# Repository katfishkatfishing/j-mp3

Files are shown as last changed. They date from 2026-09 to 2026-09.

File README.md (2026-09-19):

# J-mp3

<h2>Portable Music Player</h2>

<p align="center">
  <a href="https://github.com/user-attachments/assets/98f374b8-415b-4eb8-9580-ea03950c9d8b">
    J-mp3 Portable Music Player
  </a>
</p>
      <p>Making my own portable music player!</p>
      <p>I recently got interested in making my own electronics, and one day, I saw the Teenage Engineering TP7 field recorder. I loved the design it had, and wanted one. But I checked the price and it was wayy too expensive, so I decided to make my own, just only with the audio playing part and without the cool fancy stuff. I'm very new to this, so I couldn't replicate it very well, pls don't be too harsh on my work lol, but please feel free to give me any advice.</p>
      <p>A portable music player inspired by classic iPods, and trying to match the design style of Teenage Engineering, playing audio directly from an inserted microSD card with support for both high-fidelity analog 3.5mm output and Bluetooth audio streaming.</p>
      <p> ⚡Powered by the <strong>ESP32-S31</strong> and PCM5102A Audio DAC</p>
      <p>More projects and revisions coming soon🙏!</p>
      <p>Note: I know the rotary encoder knob is off and too long, but I temporarily have no solutions for that. 💔</p>

## Capabilities
### Microcontroller & Audio
- **ESP32-S31** (ESP32-S31 embedded, RISC-V 32-bit dual-coremicroprocessor, up to 320 MHz, 2.4 GHz Wi-Fi & Bluetooth 5.4 (LE))
- **PCM5102A** Audio Stereo DAC (32-bit, 384kHz high-resolution audio)
- **TDA1308** Class-AB stereo headphone driver amplifier
- **PJ-320B** 3.5mm headphone jack with analog output & Bluetooth audio support

### Display, Controls & Storage
- **1.73" AMOLED Display** (466×466 resolution via high-speed QSPI)
- **EC11E Rotary Encoder** with integrated push button for scroll navigation
- **MicroSD Card Socket** (Hirose DM3AT push-push) for onboard music storage

### Power & Battery Management
- **TP4056** Li-Ion battery charging IC with thermistor temperature sensing
- **DW01A + FS8205A** integrated battery protection (overcharge, overdischarge, overcurrent)
- **TPS2121** Power Multiplexer / Ideal Diode Controller (seamless automatic switching between USB-C and battery)
- **TPS61023** Synchronous boost converter & low-noise **RT9080-33** LDO regulators
- Supports 3.7V LiPo battery (705050 3000mAh)
- USB Type-C receptacle for charging and power input

## J-mp3 PCB
### Schematic
J-mp3 Schematic 1

J-mp3 Schematic 2

J-mp3 Schematic 3

J-mp3 Schematic 4

## BOM

| Item | Parts | Qty. | Price per lot (USD) | Source |
| :--- | :--- | :--- | :--- | :--- |
| Audio jack female | PJ-320B | 1 | 3.27 | https://www.aliexpress.com/item/1005010463642476.html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 |
| Dual N-channel MOSFET | FS8205A | 1 | 1.59 | https://www.aliexpress.com/item/1005006375737459.html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 |
| Ideal Diode Controller | TPS2121RUXR | 1 | 2.09 | https://www.aliexpress.com/item/1005010183114644.html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 |
| ESP32 MCU unit | ESP32-S31-WROOM-3 | 1 | 5.00 | https://www.aliexpress.com/item/1005012434557649.html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 |
| Boost Voltage Converter | TPS61023DRLR | 1 | 0.18 | https://www.aliexpress.com/item/1005008589999406.html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 |
| Ceramic capacitor SMD | 1uF 0402 | 8 | 2.04 | https://www.aliexpress.com/item/1005012364450156.html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 |
| P-Channel MOSFET | AO3401A | 1 | 1.99 | https://www.aliexpress.com/item/1005008388291353.html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 |
| Diode | 1N4148 | 2 | 1.97 | https://www.aliexpress.com/item/1005007160563285.html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 |
| Audio Stereo DAC | PCM5102A | 1 | 4.46 | https://www.aliexpress.com/item/1005006267865363.html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 |
| Headphone Driver Amplifier | TDA1308 | 1 | 2.08 | https://www.aliexpress.com/item/33051574290.html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 |
| Bipolar transistor symbol | NPN SOT-23 | 1 | 5.12 | https://www.aliexpress.com/item/1005012628572946.html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 |
| Generic connector, 02x12 | Conn_02x12_Counter_Clockwise | 1 | 1.50 | https://www.aliexpress.com/item/1005007611939409.html |
| Generic connector, 01x04 | Conn_01x04_Pin | 1 | 1.17 | https://www.aliexpress.com/item/1005012793102722.html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 |
| Inductor SMD | 2.2uH 0603 | 1 | 2.14 | https://www.aliexpress.com/item/1005004840798951.html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 |
| Linear Voltage Regulator | RT9080-33GJ5 | 2 | 1.53 | https://www.aliexpress.com/item/1005004159688937.html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 |
| Micro SD Card Socket | Hirose DM3AT-SF-PEJM5 | 1 | 1.20 | https://www.aliexpress.com/item/1005008529231123.html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 |
| Battery protection | DW01A | 1 | 2.54 | https://www.aliexpress.com/item/1005008626342372.html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 |
| Capacitor Tantalum SMD | 100uF 3528-12 (Metric) | 1 | 4.05 | https://my.mouser.com/en/ProductDetail/Vishay-Sprague/293D107X9004B2TE3?qs=N31o%252Bt096guiYtrI%2FhDC5g%3D%3D |
| Capacitor Tantalum SMD | 10uF 0603 | 4 | 9.68 | https://www.aliexpress.com/item/1005003344584575.html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 |
| Push button switch | SW-SMD_TC-1101V-C-B-W | 1 | 0.40 | https://item.szlcsc.com/300030.html |
| Push button switch SMD | SW_SPST_B3U-1000P | 2 | 1.46 | https://www.aliexpress.com/item/1005009548875400.html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 |
| Ceramic resistor SMD | 10k 0805 | 13 | 1.99 | https://www.aliexpress.com/item/1005007183002569.html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 |
| Ceramic resistor SMD | 2k 0603 | 1 | 1.80 | https://www.aliexpress.com/item/1005003529112557.html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 |
| Ceramic resistor SMD | 82k 0805 | 1 | 2.03 | https://www.aliexpress.com/item/1005007183002569.html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 |
| Ceramic resistor SMD | 100 0402 | 1 | 1.38 | https://www.aliexpress.com/item/1005003721873929.html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 |
| Ceramic resistor SMD | 3.9k 0402 | 4 | 1.38 | https://www.aliexpress.com/item/1005003721873929.html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 |
| Ceramic resistor SMD | 1m 0603 | 1 | 1.48 | https://www.aliexpress.com/item/1005010109041806.html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 |
| Ceramic resistor SMD | 5k1 0603 | 2 | 1.75 | https://www.aliexpress.com/item/1005003529112557.html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 |
| Ceramic resistor SMD | 1k 0402 | 1 | 1.38 | https://www.aliexpress.com/item/1005003721873929.html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 |
| Ceramic resistor SMD | 100k 0805 | 6 | 2.00 | https://www.aliexpress.com/item/1005007183002569.html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 |
| Ceramic resistor SMD | 4.7k 0805 | 1 | 2.00 | https://www.aliexpress.com/item/1005007183002569.html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 |
| Ceramic resistor SMD | 470 0603 | 2 | 1.80 | https://www.aliexpress.com/item/1005003529112557.html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 |
| Ceramic resistor SMD | 43k 0805 | 1 | 2.03 | https://www.aliexpress.com/item/1005007183002569.html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 |
| Ceramic resistor SMD | 732k 0603 | 1 | 2.10 | https://www.aliexpress.com/item/1005005459557840.html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 |
| Rotary encoder with switch | EC11E | 1 | 2.94 | https://www.aliexpress.com/item/32976046900.html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 |
| Single-cell battery | 755060 LiPo 3000mAh | 1 | 8.90 | https://www.aliexpress.com/item/1005006259194674.html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 |
| Li-lon Battery Charger | TP4056 | 1 | 0.52 | https://www.aliexpress.com/item/1005005487915175.html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 |
| Thermistor | 10k 0402 | 1 | 2.81 | https://www.aliexpress.com/item/1005010466857933.html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 |
| Ceramic capacitor SMD | 100nF 0603 | 4 | 2.01 | https://www.aliexpress.com/item/1005007660078779.html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 |
| Ceramic capacitor SMD | 10uF 0805 | 5 | 2.64 | https://www.aliexpress.com/item/1005012364450156.html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 |
| Ceramic capacitor SMD | 1uF 0805 | 3 | 2.35 | https://www.aliexpress.com/item/1005012364450156.html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 |
| Ceramic capacitor SMD | 10nF 0603 | 1 | 2.00 | https://www.aliexpress.com/item/1005007660078779.html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 |
| Ceramic capacitor SMD | 22uF 0805 | 3 | 3.55 | https://www.aliexpress.com/item/1005012364450156.html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 |
| Ceramic capacitor SMD | 0.1uF 0805 | 2 | 1.43 | https://www.aliexpress.com/item/1005006142309480.html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 |
| Ceramic capacitor SMD | 100uF 0805 | 2 | 13.72 | https://www.aliexpress.com/item/1005005590636993.html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 |
| Ceramic capacitor SMD | 0.1uF 0201 | 4 | 0.95 | https://www.aliexpress.com/item/1005008499718166.html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 |
| Ceramic capacitor SMD | 2.2uF 0603 | 2 | 2.03 | https://www.aliexpress.com/item/1005007660078779.html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 |
| Ceramic capacitor SMD | 1nF 0603 | 1 | 1.98 | https://www.aliexpress.com/item/1005007660078779.html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 |
| Ceramic capacitor SMD | 2.2nF 0805 | 2 | 3.04 | https://www.aliexpress.com/item/33039604868.html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 |
| Ceramic capacitor SMD | 100pF 0603 | 1 | 2.03 | https://www.aliexpress.com/item/1005007660078779.html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 |
| USBType-C Receptacle | USB4125-GF-A | 1 | 0.60 | https://www.digikey.my/en/products/detail/gct/USB4125-GF-A/13547388 |
| AMOLED Display | 1.73 inch 466x466 QSPI | 1 | 7.47 | https://item.taobao.com/item.htm?id=952177467095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 |
| Total+Shipping+Tax | - | - | 139.55± | - |

### Footprint
<table>
  <tr>
    <td>
      J-mp3 Footprint Front
    </td>
    <td>
      J-mp3 Footprint Back
    </td>
  </tr>
  <tr>
    <td>
      J-mp3 Inner Layer 1
    </td>
    <td>
      J-mp3 Inner Layer 2
    </td>
  </tr>
</table>

### 3D View
<table>
  <tr>
    <td>
      J-mp3 PCB Top
    </td>
    <td>
      J-mp3 PCB Bottom
    </td>
  </tr>
  <tr>
    <td>
      J-mp3 Enclosure Top
    </td>
    <td>
      J-mp3 Enclosure Bottom
    </td>
  </tr>
  <tr>
    <td>
      J-mp3 Enclosure Side 1
    </td>
    <td>
      J-mp3 Enclosure Side 2
    </td>
  </tr>
</table>

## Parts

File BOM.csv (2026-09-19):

Description | Value | Qty | Price per lot(USD) | Source
Audio jack female | PJ-320B | 1 | 3.27 | https://www.aliexpress.com/item/1005010463642476.html
Dual N-channel MOSFET | FS8205A | 1 | 1.59 | https://www.aliexpress.com/item/1005006375737459.html
Ideal Diode Controller | TPS2121RUXR | 1 | 2.09 | https://www.aliexpress.com/item/1005010183114644.html
ESP32 MCU unit | ESP32-S31-WROOM-3 | 1 | 5.00 | https://www.aliexpress.com/item/1005012434557649.html?srcSns=sns_Copy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
Boost Voltage Converter | TPS61023DRLR | 1 | 0.18 | https://www.aliexpress.com/item/1005008589999406.html
Ceramic capacitor SMD | 1uF 0402 | 8 | 2.04 | https://www.aliexpress.com/item/1005012364450156.html
P-Channel MOSFET | AO3401A | 1 | 1.99 | https://www.aliexpress.com/item/1005008388291353.html
Diode | 1N4148 | 2 | 1.97 | https://www.aliexpress.com/item/1005007160563285.html
Audio Stereo DAC | PCM5102A | 1 | 4.46 | https://www.aliexpress.com/item/1005006267865363.html?scm_id=1007.40050.354490.0&scm-url=1007.40050.354490.0
Headphone Driver Amplifier | TDA1308 | 1 | 2.08 | https://www.aliexpress.com/item/33051574290.html
Bipolar transistor symbol | NPN SOT-23 | 1 | 5.12 | https://www.aliexpress.com/item/1005012628572946.html
Generic connector, 02x12 | Conn_02x12_Counter_Clockwise | 1 | 1.50 | https://www.aliexpress.com/item/1005007611939409.html
Generic connector, 01x04 | Conn_01x04_Pin | 1 | 1.17 | https://www.aliexpress.com/item/1005012793102722.html
Inductor SMD | 2.2uH 0603 | 1 | 2.14 | https://www.aliexpress.com/item/1005004840798951.html
Linear Voltage Regulator | RT9080-33GJ5 | 2 | 1.53 | https://www.aliexpress.com/item/1005004159688937.html
Micro SD Card Socket | Hirose DM3AT-SF-PEJM5 | 1 | 1.20 | https://www.aliexpress.com/item/1005008529231123.html
Battery protection | DW01A | 1 | 2.54 | https://www.aliexpress.com/item/1005008626342372.html
Capacitor Tantalum SMD | 100uF 3528-12 (Metric) | 1 | 4.05 | https://my.mouser.com/en/ProductDetail/Vishay-Sprague/293D107X9004B2TE3?qs=N31o%252Bt096guiYtrI%2FhDC5g%3D%3D
Capacitor Tantalum SMD | 10uF 0603 | 4 | 9.68 | https://www.aliexpress.com/item/1005003344584575.html
Push button switch | SW-SMD_TC-1101V-C-B-W | 1 | 0.40 | https://item.szlcsc.com/300030.html
Push button switch SMD | SW_SPST_B3U-1000P | 2 | 1.46 | https://www.aliexpress.com/item/1005009548875400.html
Ceramic resistor SMD | 10k 0805 | 13 | 1.99 | https://www.aliexpress.com/item/1005007183002569.html
Ceramic resistor SMD | 2k 0603 | 1 | 1.80 | https://www.aliexpress.com/item/1005003529112557.html
Ceramic resistor SMD | 82k 0805 | 1 | 2.03 | https://www.aliexpress.com/item/1005007183002569.html
Ceramic resistor SMD | 100 0402 | 1 | 1.38 | https://www.aliexpress.com/item/1005003721873929.html
Ceramic resistor SMD | 3.9k 0402 | 4 | 1.38 | https://www.aliexpress.com/item/1005003721873929.html
Ceramic resistor SMD | 1m 0603 | 1 | 1.48 | https://www.aliexpress.com/item/1005010109041806.html
Ceramic resistor SMD | 5k1 0603 | 2 | 1.75 | https://www.aliexpress.com/item/1005003529112557.html
Ceramic resistor SMD | 1k 0402 | 1 | 1.38 | https://www.aliexpress.com/item/1005003721873929.html
Ceramic resistor SMD | 100k 0805 | 6 | 2.00 | https://www.aliexpress.com/item/1005007183002569.html
Ceramic resistor SMD | 4.7k 0805 | 1 | 2.00 | https://www.aliexpress.com/item/1005007183002569.html
Ceramic resistor SMD | 470 0603 | 2 | 1.80 | https://www.aliexpress.com/item/1005003529112557.html
Ceramic resistor SMD | 43k 0805 | 1 | 2.03 | https://www.aliexpress.com/item/1005007183002569.html
Ceramic resistor SMD | 732k 0603 | 1 | 2.10 | https://www.aliexpress.com/item/1005005459557840.html
Rotary encoder with switch | EC11E | 1 | 2.94 | https://www.aliexpress.com/item/32976046900.html?scm_id=1007.14452.396806.0&scm-url=1007.14452.396806.0
Single-cell battery | 405070 LiPo 3000mAh | 1 | 8.90 | https://www.aliexpress.com/item/1005006259194674.html
Li-lon Battery Charger | TP4056 | 1 | 0.52 | https://www.aliexpress.com/item/1005005487915175.html
Thermistor | 10k 0402 | 1 | 2.81 | https://www.aliexpress.com/item/1005010466857933.html
Ceramic capacitor SMD | 100nF 0603 | 4 | 2.01 | https://www.aliexpress.com/item/1005007660078779.html
Ceramic capacitor SMD | 10uF 0805 | 5 | 2.64 | https://www.aliexpress.com/item/1005012364450156.html
Ceramic capacitor SMD | 1uF 0805 | 3 | 2.35 | https://www.aliexpress.com/item/1005012364450156.html
Ceramic capacitor SMD | 10nF 0603 | 1 | 2.00 | https://www.aliexpress.com/item/1005007660078779.html
Ceramic capacitor SMD | 22uF 0805 | 3 | 3.55 | https://www.aliexpress.com/item/1005012364450156.html
Ceramic capacitor SMD | 0.1uF 0805 | 2 | 1.43 | https://www.aliexpress.com/item/1005006142309480.html
Ceramic capacitor SMD | 100uF 0805 | 2 | 13.72 | https://www.aliexpress.com/item/1005005590636993.html
Ceramic capacitor SMD | 0.1uF 0201 | 4 | 0.95 | https://www.aliexpress.com/item/1005008499718166.html
Ceramic capacitor SMD | 2.2uF 0603 | 2 | 2.03 | https://www.aliexpress.com/item/1005007660078779.html
Ceramic capacitor SMD | 1nF 0603 | 1 | 1.98 | https://www.aliexpress.com/item/1005007660078779.html
Ceramic capacitor SMD | 2.2nF 0805 | 2 | 3.04 | https://www.aliexpress.com/item/33039604868.html
Ceramic capacitor SMD | 100pF 0603 | 1 | 2.03 | https://www.aliexpress.com/item/1005007660078779.html
USBType-C Receptacle | USB4125-GF-A | 1 | 0.60 | https://www.digikey.my/en/products/detail/gct/USB4125-GF-A/13547388
AMOLED Display | 1.73 inch 466x466 QSPI | 1 | 7.47 | https://item.taobao.com/item.htm?id=952177467095&xxc=shop

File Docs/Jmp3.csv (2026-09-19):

Reference | Qty | Value | Footprint | Datasheet
Audio1 | 1 | PJ-320B | easyeda2kicad:AUDIO-SMD_PJ-320B_C2884998 | https://lcsc.com/product-detail/Audio-Connectors_3-5mmCloth-headphone-jack_C18594.html
BT1 | 1 | 755060 LiPo 3000mAh | Connector_JST:JST_EH_S2B-EH_1x02_P2.50mm_Horizontal
C16 | 1 | 10nF | Capacitor_SMD:C_0603_1608Metric_Pad1.08x0.95mm_HandSolder
C22 | 1 | 100uF | Capacitor_Tantalum_SMD:CP_EIA-3528-12_Kemet-T_HandSolder
C37 | 1 | 1nF | Capacitor_SMD:C_0603_1608Metric_Pad1.08x0.95mm_HandSolder
C40 | 1 | 0.1nF | Capacitor_SMD:C_0603_1608Metric_Pad1.08x0.95mm_HandSolder
J2 | 1 | USB_C_Receptacle_PowerOnly_6P | Connector_USB:USB_C_Receptacle_GCT_USB4125-xx-x-0190_6P_TopMnt_Horizontal | https://www.usb.org/sites/default/files/documents/usb_type-c.zip
J4 | 1 | Micro_SD_Card_Det2 | Connector_Card:microSD_HC_Hirose_DM3AT-SF-PEJM5 | https://www.hirose.com/en/product/document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
J5 | 1 | Conn_01x04_Pin | Connector_PinHeader_1.00mm:PinHeader_1x04_P1.00mm_Horizontal
J6 | 1 | Conn_02x12_Counter_Clockwise | OK-23GM024-04:CONN-SMD_OK-23GM024-04
L1 | 1 | 2.2uH | Inductor_SMD:L_0603_1608Metric_Pad1.05x0.95mm_HandSolder
Q1 | 1 | FS8205A | FS8205A:SOP65P640X120-8N
Q2 | 1 | NPN | PCM_JLCPCB:Q_SOT-23 | https://ngspice.sourceforge.io/docs/ngspice-html-manual/manual.xhtml#cha_BJTs
Q3 | 1 | AO3401A | Package_TO_SOT_SMD:SOT-23 | http://www.aosmd.com/pdfs/datasheet/AO3401A.pdf
R6 | 1 | 2k | Resistor_SMD:R_0603_1608Metric_Pad0.98x0.95mm_HandSolder
R7 | 1 | 82k | Resistor_SMD:R_0805_2012Metric_Pad1.20x1.40mm_HandSolder
R8 | 1 | 100 | Resistor_SMD:R_0402_1005Metric_Pad0.72x0.64mm_HandSolder
R11 | 1 | 1m | Resistor_SMD:R_0603_1608Metric_Pad0.98x0.95mm_HandSolder
R15 | 1 | 1k | Resistor_SMD:R_0402_1005Metric_Pad0.72x0.64mm_HandSolder
R21 | 1 | 4.7k | Resistor_SMD:R_0805_2012Metric_Pad1.20x1.40mm_HandSolder
R33 | 1 | 43k | Resistor_SMD:R_0805_2012Metric_Pad1.20x1.40mm_HandSolder
R37 | 1 | 732k | Resistor_SMD:R_0603_1608Metric_Pad0.98x0.95mm_HandSolder
SW1 | 1 | Power Button | sidebutton:SW-SMD_TC-1101V-C-B-W
SW2 | 1 | RotaryEncoder_Switch | Rotary_Encoder:RotaryEncoder_Alps_EC11E-Switch_Vertical_H20mm
TH1 | 1 | 10k | THERM:THERM_NTCG103JF103FT1
U1 | 1 | TP4056 | Package_SO:SOP-8-1EP_4.57x4.57mm_P1.27mm_EP4.57x4.45mm | https://datasheet.lcsc.com/szlcsc/1906261508_Nanjing-Extension-Microelectronics-TP4056-42-ESOP8_C16581.pdf
U2 | 1 | TPS2121RUXR | footprints:RUX0012A | https://www.ti.com/lit/gpn/tps2121
U3 | 1 | DW01A | Package_TO_SOT_SMD:SOT-23-6 | https://hmsemi.com/downfile/DW01A.PDF
U4 | 1 | TDA1308 | TDA1308:SO8
U5 | 1 | PCM5102A | Package_SO:TSSOP-20_4.4x6.5mm_P0.65mm | https://www.ti.com/lit/ds/symlink/pcm5102a.pdf
U6 | 1 | ESP32-S31-WROOM-3_C9900281993 | Library:esp32s31wroom3 | https://www.lcsc.com/datasheet/C9900281993.pdf
U7 | 1 | TPS61023DRLR | TPS61023:DRL0006A | https://www.ti.com/lit/gpn/tps61023
C21,C23 | 2 | 0.1uF | Capacitor_SMD:C_0805_2012Metric_Pad1.18x1.45mm_HandSolder
C25,C26 | 2 | 100uF | Capacitor_SMD:C_0805_2012Metric_Pad1.18x1.45mm_HandSolder
C33,C34 | 2 | 2.2uF | Capacitor_SMD:C_0603_1608Metric_Pad1.08x0.95mm_HandSolder
C38,C39 | 2 | 2.2nF | Capacitor_SMD:C_0805_2012Metric_Pad1.18x1.45mm_HandSolder
D1,D2 | 2 | 1N4148 | Diode_SMD:D_SOD-323 | https://assets.nexperia.com/documents/data-sheet/1N4148_1N4448.pdf
IC1,IC2 | 2 | RT9080-33GJ5 | RT9080-33:SOT94P280X100-5N
R13,R14 | 2 | 5k1 | Resistor_SMD:R_0603_1608Metric_Pad0.98x0.95mm_HandSolder
R23,R24 | 2 | 470 | Resistor_SMD:R_0603_1608Metric_Pad0.98x0.95mm_HandSolder
SW3,SW4 | 2 | SW_Push | Button_Switch_SMD:SW_SPST_B3U-1000P
C14,C20,C41 | 3 | 1uF | Capacitor_SMD:C_0805_2012Metric_Pad1.18x1.45mm_HandSolder
C19,C45,C46 | 3 | 22uF | Capacitor_SMD:C_0805_2012Metric_Pad1.18x1.45mm_HandSolder
C2,C13,C15,C43 | 4 | 100nF | Capacitor_SMD:C_0603_1608Metric_Pad1.08x0.95mm_HandSolder
C27,C29,C31,C36 | 4 | 10uF | Capacitor_SMD:C_0603_1608Metric_Pad1.08x0.95mm_HandSolder
C28,C30,C32,C35 | 4 | 0.1uF | Capacitor_SMD:C_0201_0603Metric_Pad0.64x0.40mm_HandSolder
R9,R10,R19,R20 | 4 | 3.9k | Resistor_SMD:R_0402_1005Metric_Pad0.72x0.64mm_HandSolder
C3,C10,C18,C44,C47 | 5 | 10uF | Capacitor_SMD:C_0805_2012Metric_Pad1.18x1.45mm_HandSolder
R2,R12,R16,R22,R34,R38 | 6 | 100k | Resistor_SMD:R_0805_2012Metric_Pad1.20x1.40mm_HandSolder
C1,C4,C5,C11,C12,C17,C24,C42 | 8 | 1uF | Capacitor_SMD:C_0402_1005Metric_Pad0.74x0.62mm_HandSolder
R1,R17,R18,R25,R26,R27,R28,R29,R30,R31,R32,R35,R36 | 13 | 10k | Resistor_SMD:R_0805_2012Metric_Pad1.20x1.40mm_HandSolder

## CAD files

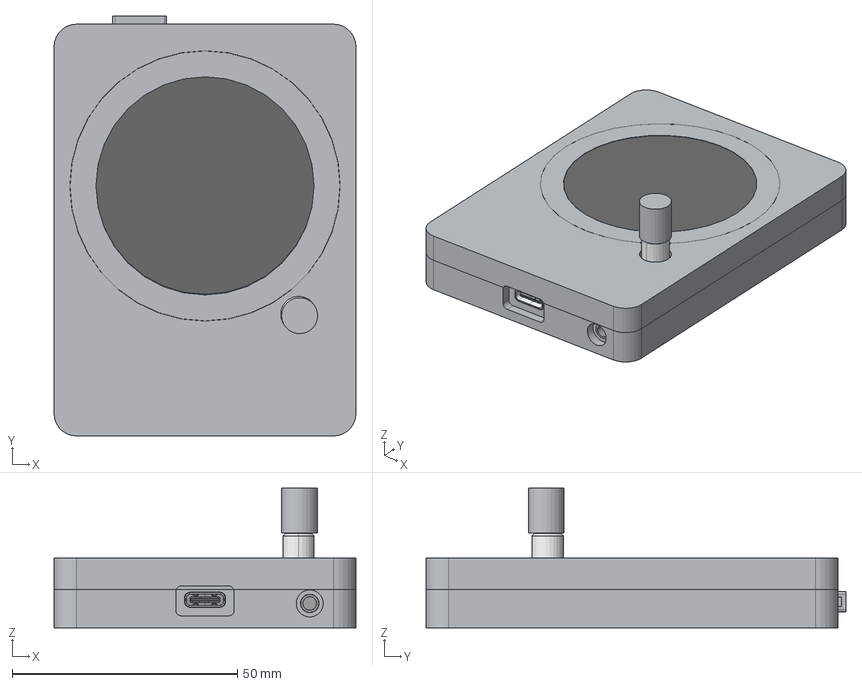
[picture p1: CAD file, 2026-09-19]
3D model/jmp3case.step
67.0 x 93.2 x 31.0 mm
Battery
C_0603_1608Metric
C_0805_2012Metric
C_0603_1608Metric002
C_0201_0603Metric
R_0603_1608Metric
R_0805_2012Metric
C_0201_0603Metric002
C_0603_1608Metric004
R_0805_2012Metric002
R_0603_1608Metric002
R_0603_1608Metric004
C_0402_1005Metric
C_0805_2012Metric002
C_0805_2012Metric004
R_0805_2012Metric004
C_0402_1005Metric002
C_0805_2012Metric006
C_0201_0603Metric004
R_0603_1608Metric006
C_0805_2012Metric008
D_SOD-323
C_0805_2012Metric010
R_0805_2012Metric006
R_0402_1005Metric
C_0805_2012Metric012
R_0805_2012Metric008
R_0402_1005Metric002
C_0805_2012Metric014
R_0805_2012Metric010
R_0402_1005Metric004
C_0805_2012Metric016
R_0805_2012Metric012
R_0805_2012Metric014
胈陆胈陋胈卤谩耞芦胈路EC11E-05SW
SOT_23
C_0805_2012Metric018
PinHeader_1x04_P100mm_Horizontal
SOT-23-6
R_0805_2012Metric016
C_0201_0603Metric006
C_0805_2012Metric020
R_0402_1005Metric006
C_0805_2012Metric022
C_0805_2012Metric024
C_0402_1005Metric004
C_0603_1608Metric006
R_0805_2012Metric018
L_0603_1608Metric
R_0805_2012Metric020
R_0805_2012Metric022
C_0603_1608Metric008
C_0603_1608Metric010
R_0805_2012Metric024
C_0402_1005Metric006
R_0805_2012Metric026
C_0603_1608Metric012
C_0805_2012Metric026
R_0805_2012Metric028
C_0603_1608Metric014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

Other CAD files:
3D model/J-mp3.step

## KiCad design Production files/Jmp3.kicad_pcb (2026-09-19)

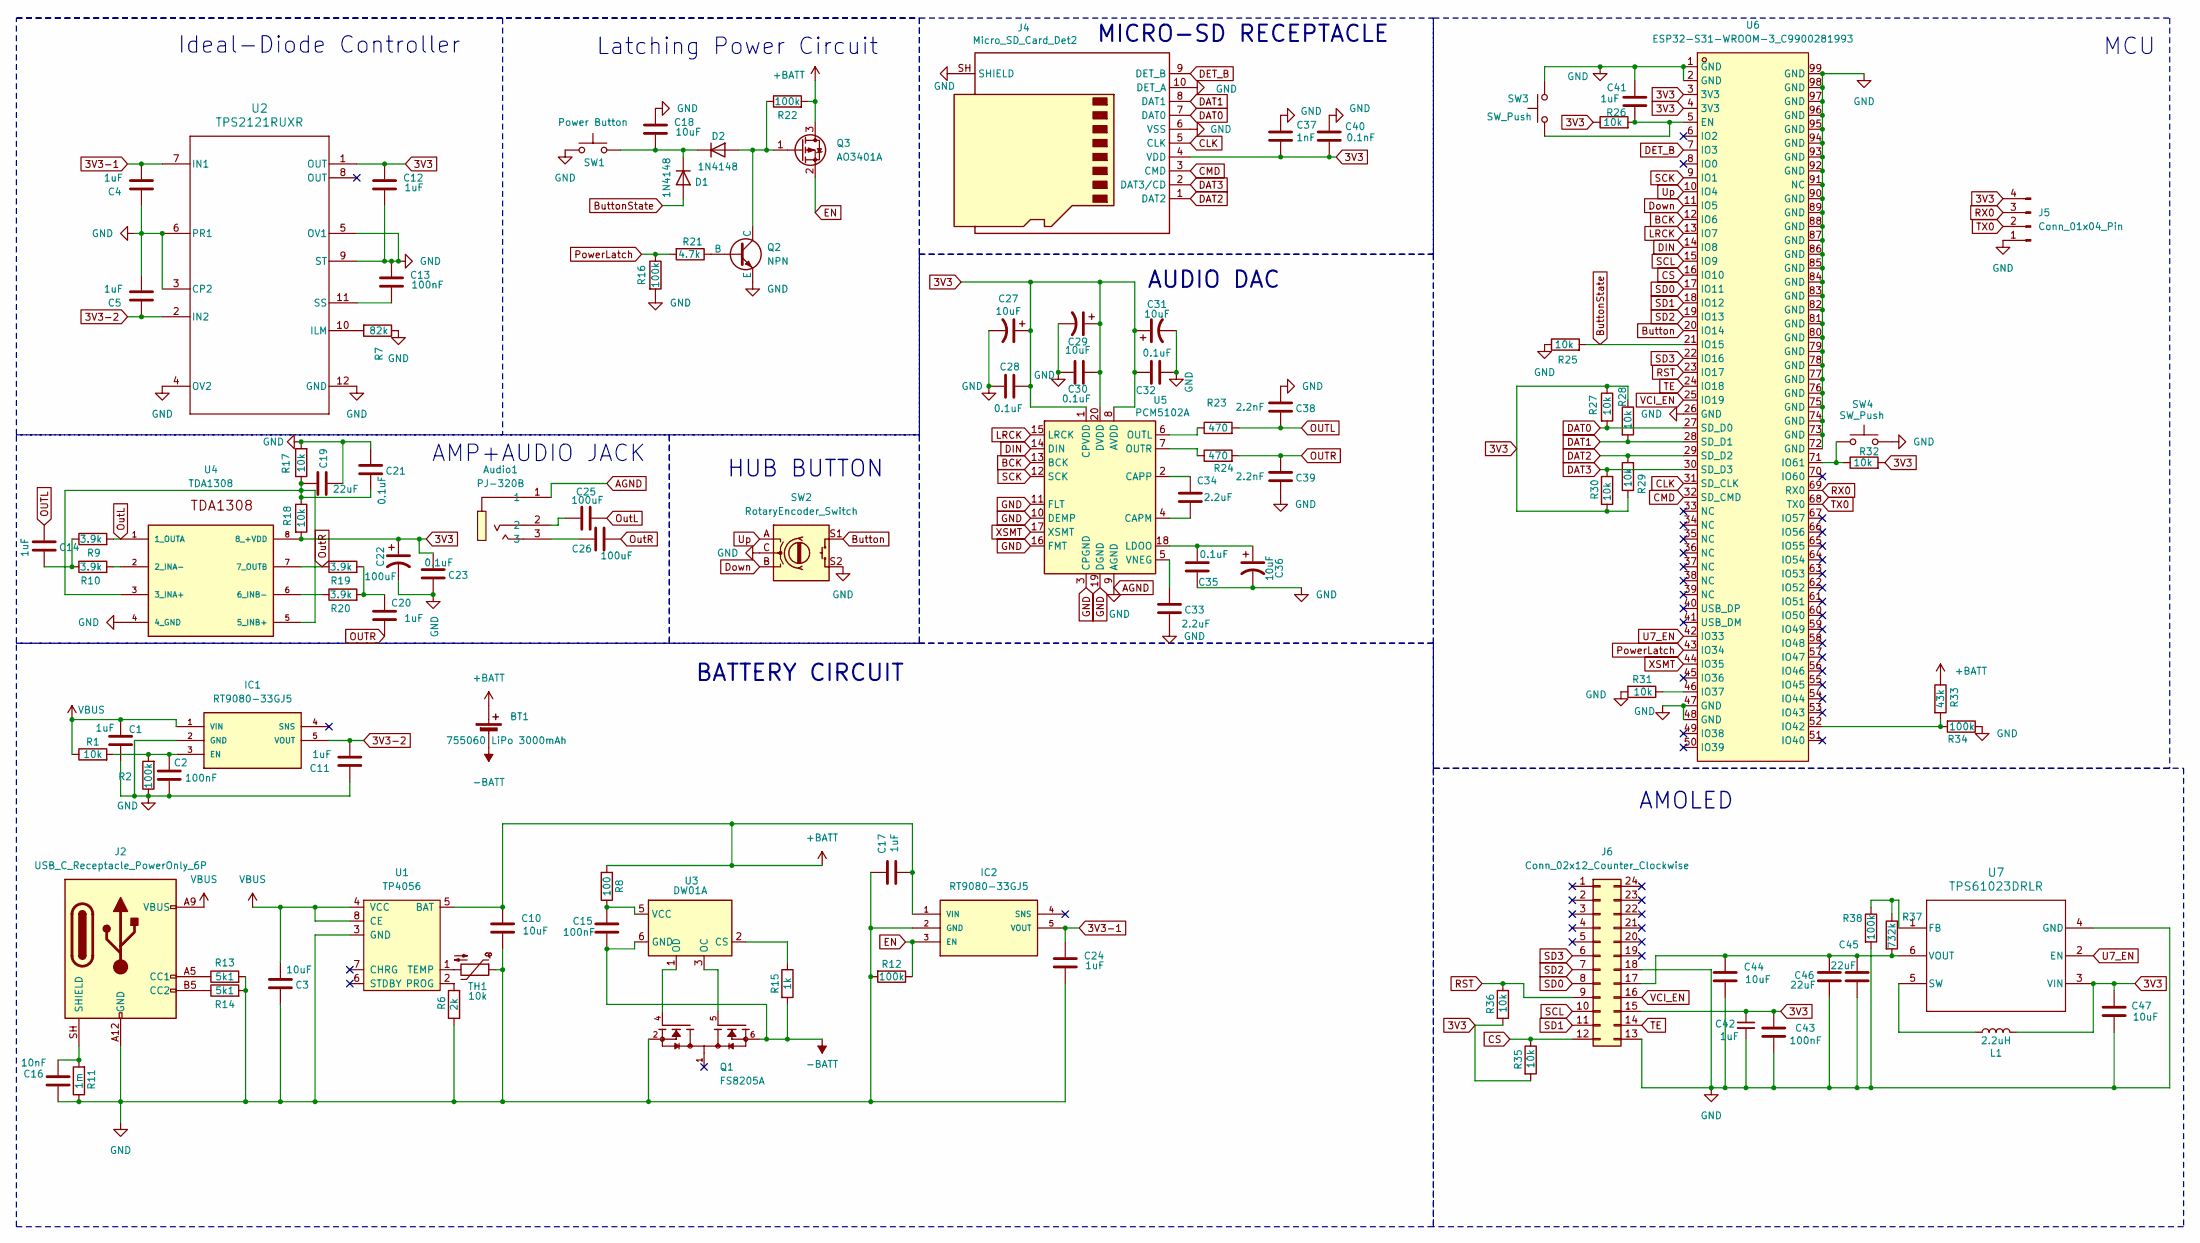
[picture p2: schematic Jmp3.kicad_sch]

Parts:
Audio1: PJ-320B; AUDIO-SMD_PJ-320B_C2884998; MPN PJ-320B贴片; LCSC Part C18594
BT1: 755060 LiPo 3000mAh; JST_EH_S2B-EH_1x02_P2.50mm_Horizontal
C1, C4, C5, C11, C12, C17, C24, C42: 1uF; C_0402_1005Metric_Pad0.74x0.62mm_HandSolder
C2, C13, C15, C43: 100nF; C_0603_1608Metric_Pad1.08x0.95mm_HandSolder
C3, C10, C18, C44, C47: 10uF; C_0805_2012Metric_Pad1.18x1.45mm_HandSolder
C14, C20, C41: 1uF; C_0805_2012Metric_Pad1.18x1.45mm_HandSolder
C16: 10nF; C_0603_1608Metric_Pad1.08x0.95mm_HandSolder
C19, C45, C46: 22uF; C_0805_2012Metric_Pad1.18x1.45mm_HandSolder
C21, C23: 0.1uF; C_0805_2012Metric_Pad1.18x1.45mm_HandSolder
C22: 100uF; CP_EIA-3528-12_Kemet-T_HandSolder
C25, C26: 100uF; C_0805_2012Metric_Pad1.18x1.45mm_HandSolder
C27, C29, C31, C36: 10uF; C_0603_1608Metric_Pad1.08x0.95mm_HandSolder
C28, C30, C32, C35: 0.1uF; C_0201_0603Metric_Pad0.64x0.40mm_HandSolder
C33, C34: 2.2uF; C_0603_1608Metric_Pad1.08x0.95mm_HandSolder
C37: 1nF; C_0603_1608Metric_Pad1.08x0.95mm_HandSolder
C38, C39: 2.2nF; C_0805_2012Metric_Pad1.18x1.45mm_HandSolder
C40: 0.1nF; C_0603_1608Metric_Pad1.08x0.95mm_HandSolder
D1, D2: 1N4148; D_SOD-323
IC1, IC2: RT9080-33GJ5; SOT94P280X100-5N
J2: USB_C_Receptacle_PowerOnly_6P; USB_C_Receptacle_GCT_USB4125-xx-x-0190_6P_TopMnt_Horizontal
J4: Micro_SD_Card_Det2; microSD_HC_Hirose_DM3AT-SF-PEJM5
J5: Conn_01x04_Pin; PinHeader_1x04_P1.00mm_Horizontal
J6: Conn_02x12_Counter_Clockwise; CONN-SMD_OK-23GM024-04
L1: 2.2uH; L_0603_1608Metric_Pad1.05x0.95mm_HandSolder
Q1: FS8205A; SOP65P640X120-8N; PARTREV 1.7
Q2: NPN; Q_SOT-23
Q3: AO3401A; SOT-23
R1, R17, R18, R25, R26, R27, R28, R29, R30, R31, R32, R35, R36: 10k; R_0805_2012Metric_Pad1.20x1.40mm_HandSolder
R2, R12, R16, R22, R34, R38: 100k; R_0805_2012Metric_Pad1.20x1.40mm_HandSolder
R6: 2k; R_0603_1608Metric_Pad0.98x0.95mm_HandSolder
R7: 82k; R_0805_2012Metric_Pad1.20x1.40mm_HandSolder
R8: 100; R_0402_1005Metric_Pad0.72x0.64mm_HandSolder
R9, R10, R19, R20: 3.9k; R_0402_1005Metric_Pad0.72x0.64mm_HandSolder
R11: 1m; R_0603_1608Metric_Pad0.98x0.95mm_HandSolder
R13, R14: 5k1; R_0603_1608Metric_Pad0.98x0.95mm_HandSolder
R15: 1k; R_0402_1005Metric_Pad0.72x0.64mm_HandSolder
R21: 4.7k; R_0805_2012Metric_Pad1.20x1.40mm_HandSolder
R23, R24: 470; R_0603_1608Metric_Pad0.98x0.95mm_HandSolder
R33: 43k; R_0805_2012Metric_Pad1.20x1.40mm_HandSolder
R37: 732k; R_0603_1608Metric_Pad0.98x0.95mm_HandSolder
SW1: Power Button; SW-SMD_TC-1101V-C-B-W
SW2: RotaryEncoder_Switch; RotaryEncoder_Alps_EC11E-Switch_Vertical_H20mm
SW3, SW4: SW_Push; SW_SPST_B3U-1000P
TH1: 10k; THERM_NTCG103JF103FT1
U1: TP4056; SOP-8-1EP_4.57x4.57mm_P1.27mm_EP4.57x4.45mm; LCSC C16581
U2: TPS2121RUXR; RUX0012A
U3: DW01A; SOT-23-6
U4: TDA1308; SO8
U5: PCM5102A; TSSOP-20_4.4x6.5mm_P0.65mm
U6: ESP32-S31-WROOM-3_C9900281993; esp32s31wroom3; MPN ESP32-S31-WROOM-3; LCSC Part C9900281993
U7: TPS61023DRLR; DRL0006A

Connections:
3V3: C12.1, C22.1, C23.1, C27.1, C28.2, C29.1, C30.2, C31.1, C32.2, C37.2, C40.2, C42.1, C43.1, C47.1, J4.4 (VDD), J5.4, J6.15, L1.2, R18.2, R26.1, R27.1, R28.1, R29.1, R30.1, R32.2, R35.2, R36.2, U2.1 (OUT), U4.8 (8_+VDD), U5.1 (CPVDD), U5.8 (AVDD), U5.20 (DVDD), U6.3 (3V3), U6.4 (3V3), U7.3 (VIN)
3V3-1: C4.2, C24.1, IC2.5 (VOUT), U2.7 (IN1)
3V3-2: C5.1, C11.2, IC1.5 (VOUT), U2.2 (IN2)
+BATT: BT1.1 (+), C10.1, C17.2, IC2.1 (VIN), Q3.3 (D), R8.2, R22.2, R33.1, U1.5 (BAT)
-BATT: BT1.2 (-), C15.2, Q1.6, Q1.7, R15.2, U3.6 (GND)
AGND: Audio1.1, C1.1, C2.2, C3.1, C4.1, C5.2, C10.2, C11.1, C12.2, C13.1, C16.1, C17.1, C18.1, C19.2, C21.1, C22.2, C23.2, C24.2, C27.2, C28.1, C29.2, C30.1, C31.2, C32.1, C33.2, C35.2, C36.2, C37.1, C38.1, C39.2, C40.1, C41.2, C42.2, C43.2, C44.2, C45.1, C46.1, C47.2, IC1.2 (GND), IC2.2 (GND), J2.A12 (GND), J2.B12 (GND), J4.6 (VSS), J4.10 (DET_A), J4.SH (SHIELD), J5.1, J6.13, J6.18, Q1.2, Q1.3, Q2.3 (E), R2.1, R6.1, R7.1, R11.1, R12.2, R13.2, R14.2, R16.2, R17.2, R25.1, R31.2, R34.1, R38.2, SW1.1, SW2.C, SW2.S2, SW3.2, SW4.2, TH1.1, U1.3 (GND), U2.3 (CP2), U2.4 (OV2), U2.5 (OV1), U2.6 (PR1), U2.9 (ST), U2.12 (GND), U4.4 (4_GND), U5.3 (CPGND), U5.9 (AGND), U5.10 (DEMP), U5.11 (FLT), U5.16 (FMT), U5.19 (DGND), U6.1 (GND), U6.2 (GND), U6.26 (GND), U6.47 (GND), U6.48 (GND), U6.72 (GND), U6.73 (GND), U6.74 (GND), U6.75 (GND), U6.76 (GND), U6.77 (GND), U6.78 (GND), U6.79 (GND), U6.80 (GND), U6.81 (GND), U6.82 (GND), U6.83 (GND), U6.84 (GND), U6.85 (GND), U6.86 (GND), U6.87 (GND), U6.88 (GND), U6.89 (GND), U6.90 (GND), U6.91 (NC), U6.92 (GND), U6.93 (GND), U6.94 (GND), U6.95 (GND), U6.96 (GND), U6.97 (GND), U6.98 (GND), U6.99 (GND), U7.4 (GND)
BCK: U5.13 (BCK), U6.12 (IO6)
Button: SW2.S1, U6.20 (IO14)
ButtonState: D1.2 (A), R25.2, U6.21 (IO15)
CLK: J4.5 (CLK), U6.31 (SD_CLK)
CMD: J4.3 (CMD), U6.32 (SD_CMD)
CS: J6.12, R35.1, U6.16 (IO10)
DAT0: J4.7 (DAT0), R27.2, U6.27 (SD_D0)
DAT1: J4.8 (DAT1), R28.2, U6.28 (SD_D1)
DAT2: J4.1 (DAT2), R29.2, U6.29 (SD_D2)
DAT3: J4.2 (DAT3/CD), R30.2, U6.30 (SD_D3)
DET_B: J4.9 (DET_B), U6.7 (IO3)
DIN: U5.14 (DIN), U6.14 (IO8)
Down: SW2.B, U6.11 (IO5)
EN: IC2.3 (EN), Q3.2 (S), R12.1
LRCK: U5.15 (LRCK), U6.13 (IO7)
unnamed: Audio1.2, C25.2
unnamed: Audio1.3, C26.1
unnamed: C14.2, R9.1, R10.1
unnamed: C20.2, R19.2, R20.2
unnamed: C18.2, D1.1 (K), D2.1 (K), SW1.2
unnamed: D2.2 (A), Q2.1 (C), Q3.1 (G), R22.1
unnamed: C2.1, IC1.3 (EN), R1.2, R2.2
unnamed: J2.A5 (CC1), R13.1
unnamed: J2.B5 (CC2), R14.1
unnamed: C16.2, J2.SH (SHIELD), R11.2
unnamed: C44.1, C45.2, C46.2, J6.17, R37.2, U7.6 (VOUT)
unnamed: Q2.2 (B), R21.1
unnamed: R6.2, U1.2 (PROG)
unnamed: TH1.2, U1.1 (TEMP)
unnamed: R7.2, U2.10 (ILM)
unnamed: C13.2, U2.11 (SS)
unnamed: R15.1, U3.2 (CS)
unnamed: Q1.5, U3.3 (OC)
unnamed: Q1.4, U3.1 (OD)
unnamed: C15.1, R8.1, U3.5 (VCC)
unnamed: R10.2, U4.2 (2_INA-)
unnamed: C19.1, C21.2, R17.1, R18.1, U4.3 (3_INA+), U4.5 (5_INB+)
unnamed: R20.1, U4.6 (6_INB-)
unnamed: C34.1, U5.4 (CAPM)
unnamed: C34.2, U5.2 (CAPP)
unnamed: C35.1, C36.1, U5.18 (LDOO)
unnamed: R23.1, U5.6 (OUTL)
unnamed: R24.1, U5.7 (OUTR)
unnamed: C33.1, U5.5 (VNEG)
unnamed: C41.1, R26.2, SW3.1, U6.5 (EN)
unnamed: R31.1, U6.46 (IO37)
unnamed: R33.2, R34.2, U6.52 (IO42)
unnamed: R32.1, SW4.1, U6.71 (IO61)
unnamed: R37.1, R38.1, U7.1 (FB)
unnamed: L1.1, U7.5 (SW)
OUTL: C14.1, C38.2, R23.2
OUTR: C20.1, C39.1, R24.2
OutL: C25.1, R9.2, U4.1 (1_OUTA)
OutR: C26.2, R19.1, U4.7 (7_OUTB)
PowerLatch: R16.1, R21.2, U6.43 (IO34)
RST: J6.9, R36.1, U6.23 (IO17)
RX0: J5.3, U6.69 (RX0)
SCK: U5.12 (SCK), U6.9 (IO1)
SCL: J6.10, U6.15 (IO9)
SD0: J6.8, U6.17 (IO11)
SD1: J6.11, U6.18 (IO12)
SD2: J6.7, U6.19 (IO13)
SD3: J6.6, U6.22 (IO16)
TE: J6.14, U6.24 (IO18)
TX0: J5.2, U6.68 (TX0)
U7_EN: U6.42 (IO33), U7.2 (EN)
Up: SW2.A, U6.10 (IO4)
VBUS: C1.2, C3.2, IC1.1 (VIN), J2.A9 (VBUS), J2.B9 (VBUS), R1.1, U1.4 (VCC), U1.8 (CE)
VCI_EN: J6.16, U6.25 (IO19)
XSMT: U5.17 (XSMT), U6.44 (IO35)

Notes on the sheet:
Ideal-Diode Controller
BATTERY CIRCUIT
AUDIO DAC
AMP+AUDIO JACK
HUB BUTTON
MICRO-SD RECEPTACLE
MCU
AMOLED
Latching Power Circuit

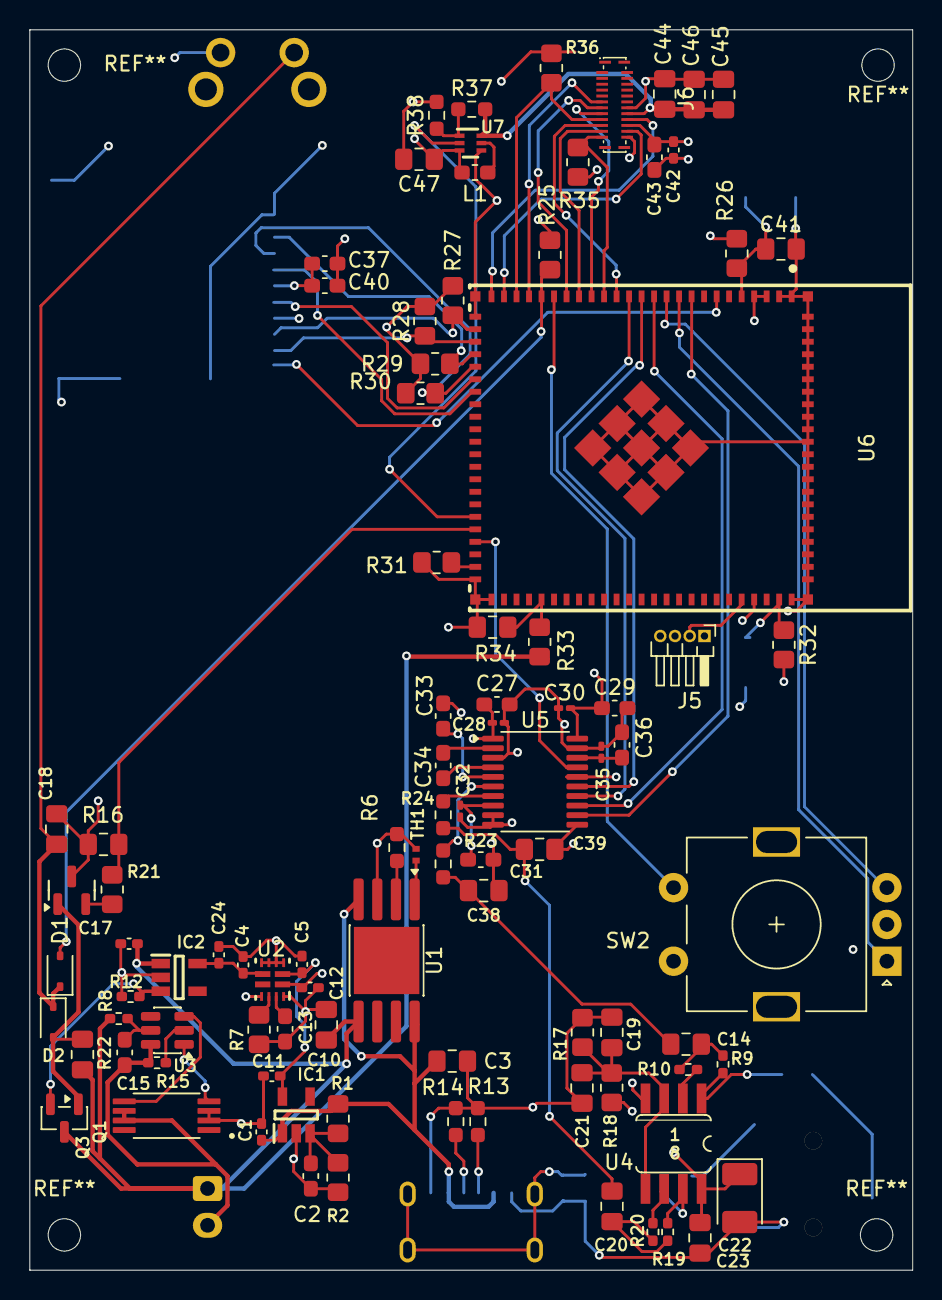
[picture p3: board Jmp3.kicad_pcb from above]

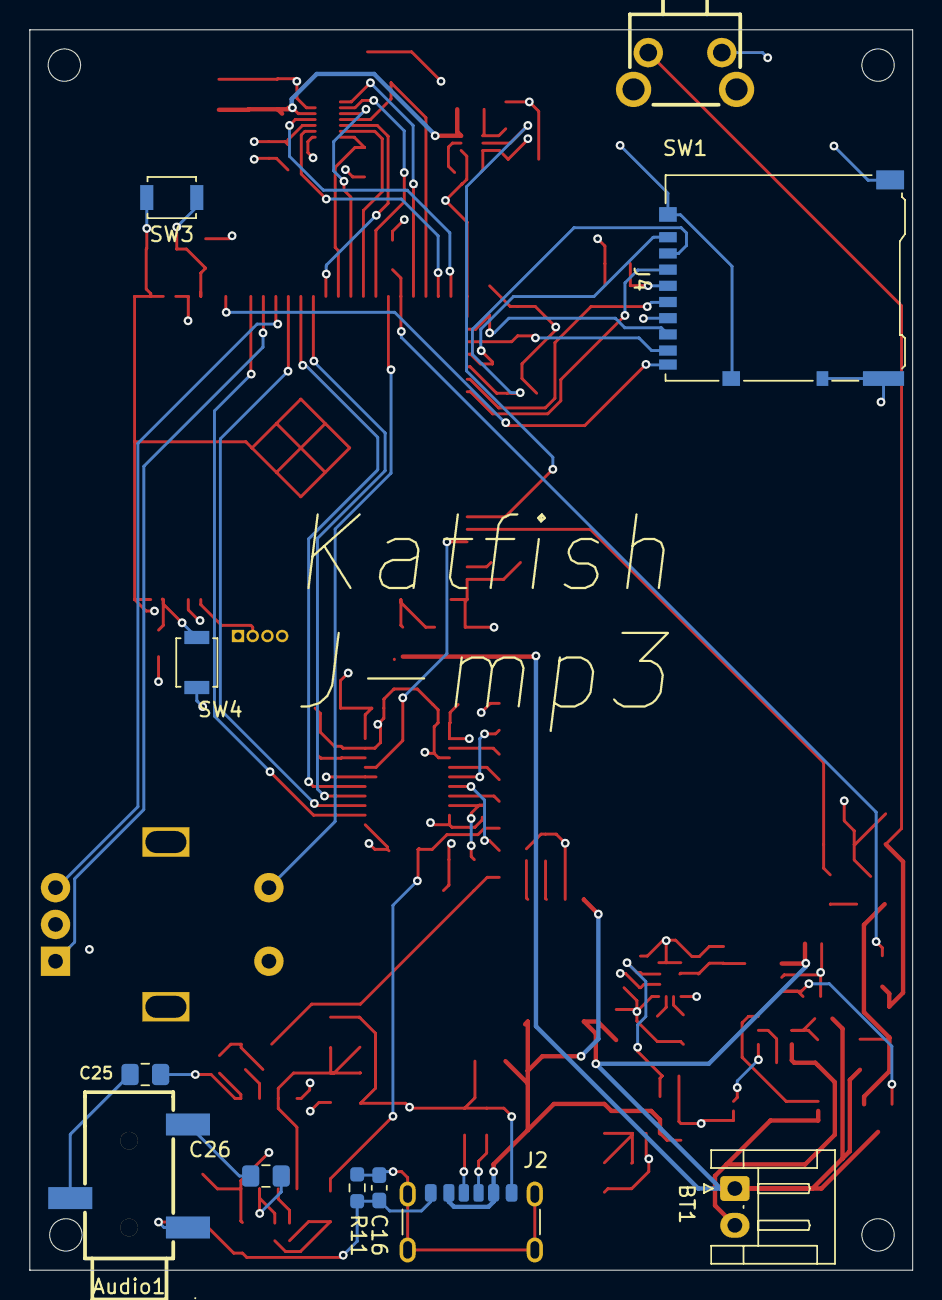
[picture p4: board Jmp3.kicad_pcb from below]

Board: 4 copper layers, 60.0 x 84.3 mm, 104 parts (11 on the bottom side), 76 nets.

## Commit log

2026-09-19 Fix table formatting in BOM section of README
2026-09-19 Added case step file
    [jmp3case.step]
